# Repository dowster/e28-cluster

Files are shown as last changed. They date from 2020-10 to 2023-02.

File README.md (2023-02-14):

# E28 Cluster Driver

E28 Cluster Driver is (going to be...) an ESP32 based driver board which allows the E28, and possibly E21/E30, cluster to be controlled via custom inputs. For the first version custom input will be done solely via CAN Bus. There won't be any hardcoded message spec, that will be configurable by the user after firmware has been flashed. 

> Main repository is at https://gitlab.com/dowster/e28-cluster

# Build Status


## Hardware

- ESP32
- [GD32VF103RBT6](https://www.mouser.com/ProductDetail/GigaDevice/GD32VF103RBT6)

# ESP IDF Version
v4.2

:)

# E28 Cluster Driver Inputs

Input to the E28 cluster driver shall be done via CAN Bus and possibly with a web based interface for diagnostics, calibration, and configuration. The CAN input shall be configurable so that any value on a can message may be mapped to any of the outputs, allowing the potential for configuring the driver with custom cluster gauge faces. IE: using the econometer to show watts / mile. 

# Instrument Cluster Outputs

## Speedometer Output

The speedometer of the E28 cluster is pulse driven. Approximately 2Hz for every MPH. IE: 50hz -> 25mph, 280hz -> 140mph. Driving the speedometer will advance the odometer automatically. It will also generate a pulse signal that is output to the SI board and the cruise control hardware. 

The speedometer operates on a [UAF 2115 IC](https://darisusgmbh.de/darisus/Elektonikshop/Datenblaetter/ITT/UAF2115.pdf). This IC is a general purpose speedoemter and mileage indidactor IC by ITT Semiconductors. It provides a constant current source to the output pin(s) 10-13 on the E28 cluster plug C2 (white), these four pins are all bridged together, shorting these to ground will provide a pulse to the speedometer. The UAF 2115 also provides an open collector NPN pulse output to drive things such as cruise control. In order to trigger a pulse the speed sensor in the differential would short to ground as each tooth of the gear passed by, these pulses must be atleast 50 microseconds in duration, the max frequency is 10Khz. On the E28 Pin 11 of UAF 2115 is connected to ground, so the division factor is 2^6, I think this is to configure how the odometer tracks distance. 

## Temperature Gauge Output

The temperature guage output will be an open collector NPN output from the E28 cluster driver. The temperature gauge is controlled by varying the current output of pin 12 on connector C1 of the E28 instrument cluster. To control this I'll either use the DAC on the ESP32 or use PWM. I have had some issues with "buzzing" when using PWM but I may just need a higher frequency. 

## Fuel Gauge Output

This is pretty much the same as the temperature gauge but with a different calibration. I'll be using a lower value resistor on the gate of this transistor since the fuel gauge requires more current. This signal is also output to the onboard computer by default. See [OBC Outputs](#OBC-Outputs) for information on how I plan to control the OBC.

## Tachometer Output

The tachometer is controleld by a simple voltage input. I'm thinking a PNP driver for this with PWM control should be fine. 

## Econometer Output

No clue how to do this one yet, haven't really looked into it. 

## Warning Indicators (On PCB)

The warning lights will be controlled via simple solid state relay circuits. Either PNP or NPN transistors controleld via shift registers to save up some pins on the ESP32, if needed. Some of the warning indicators are built onto the instrument cluster's PCB, others are controlled via lights have external wiring. 

### Charge Indicator

Could have many different functions, possibly solid when charging the pack or when the pre-charge resistor is engaged and flashing when a pack error is detected.

### Brake Warning Indicator

TODO

### High Beam Indicator

TODO

### Fog Light Indicator

TODO

### LH Turn Indicator

TODO

### RH Turn Indicator

TODO

### Low Fuel Warning Indicator 

TODO

### "Check" Active Check Control Alarm Indicator

TODO

### Oil Pressure Warning Indicator

This is probably not needed with an EV so that could be modified to be _something else_.

### "Park Brake" Indicator

TODO

### Brake Lining indicator

Haven't seen how this wires up yet, It's on the PCB.

## Warning Indicators (External Wiring)

### Left and Right turn arrows

Probably used to be used on cars where there was only one lamp to tell you that the turn indicators were on. Could be repurposed with a different logo. Background is green.

### Solid Yellow

There's no graphic on this lamp, it's in the 3rd position from left and just has a yellow or orange color filter. 

### EML

Not wired up, says "EML" in black letters with a yellow or orange color filter. 4th position from left

### Solid Green

No graphic on this indiactor, just a solid green. 6th position from left.

### ABS

If the stock ABS is kept this can stay here. Not sure if ABS is used on many swaps but I think that if it is this light may want to be used as a way to kill regen and let the motor coast while ABS figures out what to do. 

## Gearshift Indicators

Seems like even the manual clusters include this plate, or my car has been swapped with an automatic cluster. 

### Transmission Warning Indicator

Shows as a gear with an exclamation mark in the center

### P, R, N, D

Pretty self explanatory

### 3, 2, 1

Show up as individual lamps, for indicating if you've manually selected one of these gears I presume. 

### 1-2-3

This is on single indicator, I presume that it indicates you've disabled overdrive. 

# OBC Outputs

The method for driving the OBC hasn't been determined yet, two options are to just plug the OBC into the instrument cluster and let it run business as usual. The more involved, and possibly better method is to map out the pins on the OBC and manipulate that with the  E28 cluster driver. The main feature I'd like to see out of this is an accuruate range estimate based on pack state of charge and average watts/mile.

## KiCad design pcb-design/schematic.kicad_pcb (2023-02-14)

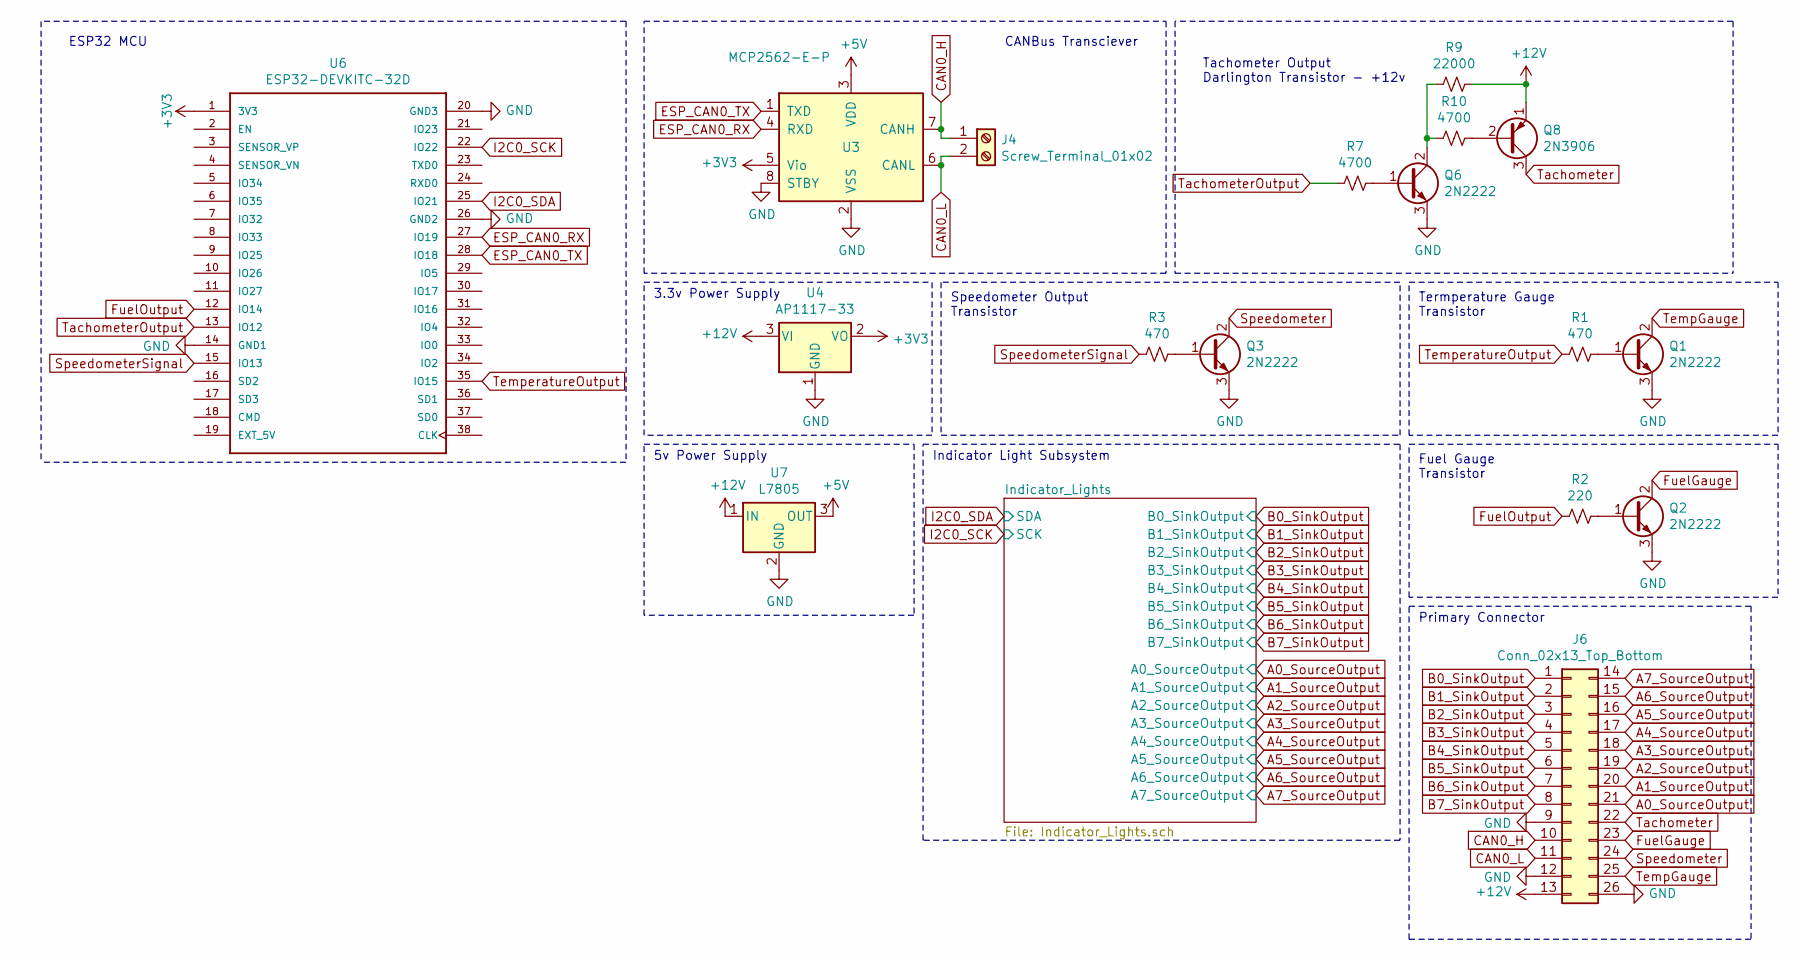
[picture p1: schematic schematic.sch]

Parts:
J4: Screw_Terminal_01x02; TerminalBlock_TE_282834-2_1x02_P2.54mm_Horizontal
J6: Conn_02x13_Top_Bottom; Connector_TE_827881-1
Q1, Q2, Q3, Q6: 2N2222; TO-92_HandSolder
Q8: 2N3906; TO-92_Inline
R1, R3: 470; R_0805_2012Metric
R2: 220; R_0805_2012Metric
R7, R10: 4700; R_0805_2012Metric
R9: 22000; R_0805_2012Metric
U3: MCP2562-E-P; DIP-8_W7.62mm
U4: AP1117-33; SIP3_11.6x8.5mm
U6: ESP32-DEVKITC-32D; MODULE_ESP32-DEVKITC-32D
U7: L7805; SIP3_11.6x8.5mm

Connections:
+5V: U3.3 (VDD), U7.3 (OUT)
+12V: J6.13, Q8.1 (E), R9.1, U4.3 (VI), U7.1 (IN); also elsewhere on the board
A0_SourceOutput: J6.21; also elsewhere on the board
A1_SourceOutput: J6.20; also elsewhere on the board
A2_SourceOutput: J6.19; also elsewhere on the board
A3_SourceOutput: J6.18; also elsewhere on the board
A4_SourceOutput: J6.17; also elsewhere on the board
A5_SourceOutput: J6.16; also elsewhere on the board
A6_SourceOutput: J6.15; also elsewhere on the board
A7_SourceOutput: J6.14; also elsewhere on the board
B0_SinkOutput: J6.1; also elsewhere on the board
B1_SinkOutput: J6.2; also elsewhere on the board
B2_SinkOutput: J6.3; also elsewhere on the board
B3_SinkOutput: J6.4; also elsewhere on the board
B4_SinkOutput: J6.5; also elsewhere on the board
B5_SinkOutput: J6.6; also elsewhere on the board
B6_SinkOutput: J6.7; also elsewhere on the board
B7_SinkOutput: J6.8; also elsewhere on the board
CAN0_H: J4.1, J6.10, U3.7 (CANH)
CAN0_L: J4.2, J6.11, U3.6 (CANL)
ESP_CAN0_RX: U3.4 (RXD), U6.27 (IO19)
ESP_CAN0_TX: U3.1 (TXD), U6.28 (IO18)
FuelGauge: J6.23, Q2.2 (C)
FuelOutput: R2.2, U6.12 (IO14)
GND: J6.9, J6.12, J6.26, Q1.3 (E), Q2.3 (E), Q3.3 (E), Q6.3 (E), U3.2 (VSS), U3.8 (STBY), U4.1 (GND), U6.14 (GND1), U6.20 (GND3), U6.26 (GND2), U7.2 (GND); also elsewhere on the board
I2C0_SCK: U6.22 (IO22); also elsewhere on the board
I2C0_SDA: U6.25 (IO21); also elsewhere on the board
unnamed: Q1.1 (B), R1.1
unnamed: Q2.1 (B), R2.1
unnamed: Q3.1 (B), R3.1
unnamed: Q6.1 (B), R7.1
unnamed: Q6.2 (C), R9.2, R10.2
unnamed: Q8.2 (B), R10.1
Speedometer: J6.24, Q3.2 (C)
SpeedometerSignal: R3.2, U6.15 (IO13)
Tachometer: J6.22, Q8.3 (C)
TachometerOutput: R7.2, U6.13 (IO12)
TempGauge: J6.25, Q1.2 (C)
TemperatureOutput: R1.2, U6.35 (IO15)

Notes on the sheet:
CANBus Transciever
Tachometer Output Darlington Transistor - +12v
3.3v Power Supply
Speedometer Output Transistor
ESP32 MCU
Termperature Gauge Transistor
Fuel Gauge Transistor
Indicator Light Subsystem
Primary Connector
5v Power Supply

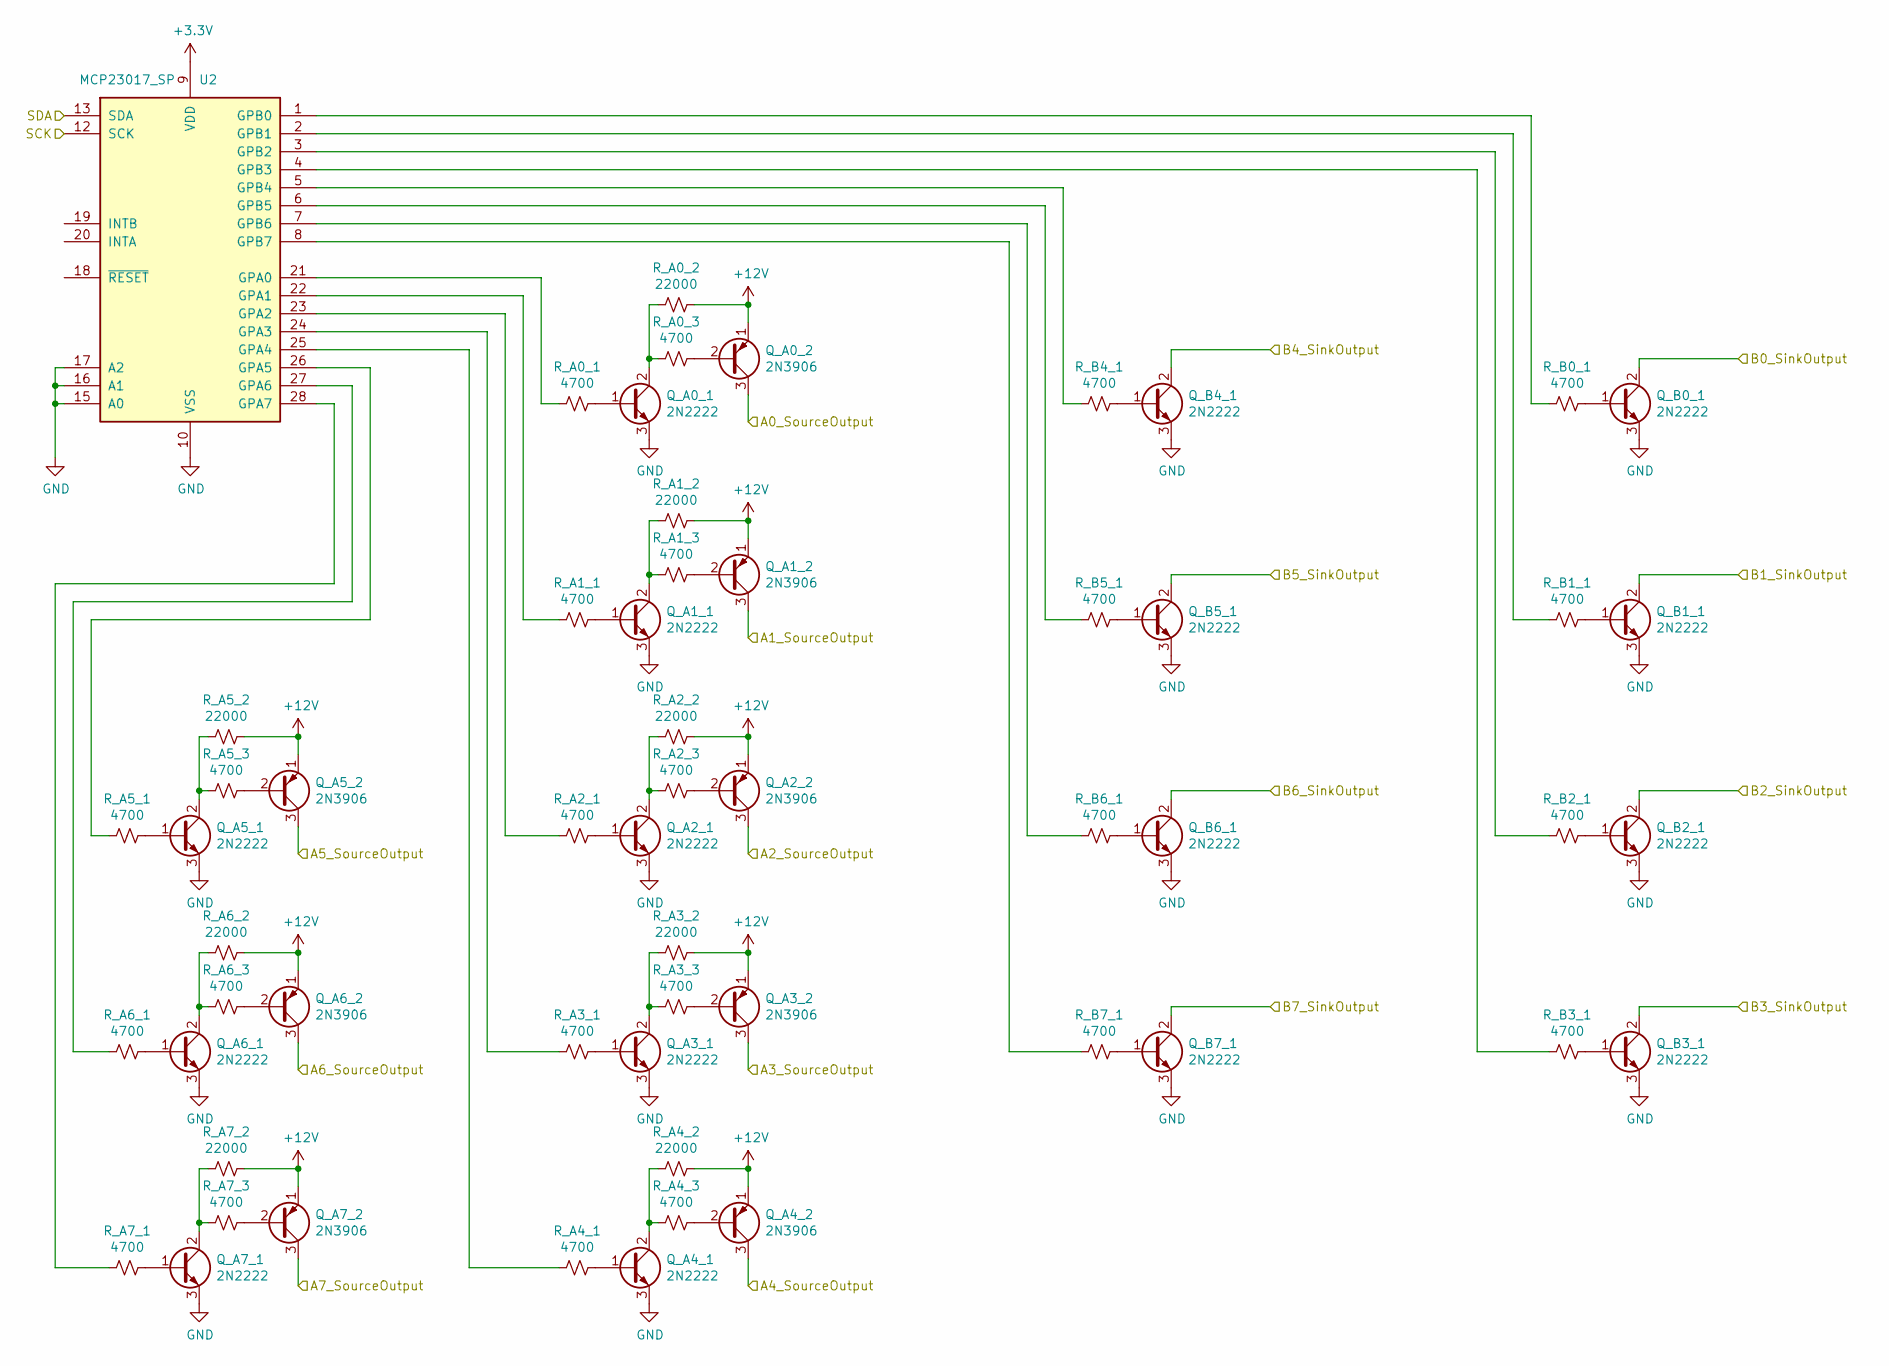
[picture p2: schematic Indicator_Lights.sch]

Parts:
Q_A0_1, Q_A1_1, Q_A2_1, Q_A3_1, Q_A4_1, Q_A5_1, Q_A6_1, Q_A7_1: 2N2222; TO-92_HandSolder
Q_A0_2, Q_A1_2, Q_A2_2, Q_A3_2, Q_A4_2, Q_A5_2, Q_A6_2, Q_A7_2: 2N3906; TO-92_Inline
Q_B0_1, Q_B1_1, Q_B2_1, Q_B3_1, Q_B4_1, Q_B5_1, Q_B6_1, Q_B7_1: 2N2222; TO-92_HandSolder
R_A0_1, R_A0_3, R_A1_1, R_A1_3, R_A2_1, R_A2_3, R_A3_1, R_A3_3, R_A4_1, R_A4_3, R_A5_1, R_A5_3, R_A6_1, R_A6_3, R_A7_1, R_A7_3: 4700; R_0805_2012Metric
R_A0_2, R_A1_2, R_A2_2, R_A3_2, R_A4_2, R_A5_2, R_A6_2, R_A7_2: 22000; R_0805_2012Metric
R_B0_1, R_B1_1, R_B2_1, R_B3_1, R_B4_1, R_B5_1, R_B6_1, R_B7_1: 4700; R_0805_2012Metric
U2: MCP23017_SP; DIP-28_W7.62mm

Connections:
+12V: Q_A0_2.1 (E), Q_A1_2.1 (E), Q_A2_2.1 (E), Q_A3_2.1 (E), Q_A4_2.1 (E), Q_A5_2.1 (E), Q_A6_2.1 (E), Q_A7_2.1 (E), R_A0_2.1, R_A1_2.1, R_A2_2.1, R_A3_2.1, R_A4_2.1, R_A5_2.1, R_A6_2.1, R_A7_2.1; also elsewhere on the board
A0_SourceOutput: Q_A0_2.3 (C); also elsewhere on the board
A1_SourceOutput: Q_A1_2.3 (C); also elsewhere on the board
A2_SourceOutput: Q_A2_2.3 (C); also elsewhere on the board
A3_SourceOutput: Q_A3_2.3 (C); also elsewhere on the board
A4_SourceOutput: Q_A4_2.3 (C); also elsewhere on the board
A5_SourceOutput: Q_A5_2.3 (C); also elsewhere on the board
A6_SourceOutput: Q_A6_2.3 (C); also elsewhere on the board
A7_SourceOutput: Q_A7_2.3 (C); also elsewhere on the board
B0_SinkOutput: Q_B0_1.2 (C); also elsewhere on the board
B1_SinkOutput: Q_B1_1.2 (C); also elsewhere on the board
B2_SinkOutput: Q_B2_1.2 (C); also elsewhere on the board
B3_SinkOutput: Q_B3_1.2 (C); also elsewhere on the board
B4_SinkOutput: Q_B4_1.2 (C); also elsewhere on the board
B5_SinkOutput: Q_B5_1.2 (C); also elsewhere on the board
B6_SinkOutput: Q_B6_1.2 (C); also elsewhere on the board
B7_SinkOutput: Q_B7_1.2 (C); also elsewhere on the board
GND: Q_A0_1.3 (E), Q_A1_1.3 (E), Q_A2_1.3 (E), Q_A3_1.3 (E), Q_A4_1.3 (E), Q_A5_1.3 (E), Q_A6_1.3 (E), Q_A7_1.3 (E), Q_B0_1.3 (E), Q_B1_1.3 (E), Q_B2_1.3 (E), Q_B3_1.3 (E), Q_B4_1.3 (E), Q_B5_1.3 (E), Q_B6_1.3 (E), Q_B7_1.3 (E), U2.10 (VSS), U2.15 (A0), U2.16 (A1), U2.17 (A2); also elsewhere on the board
I2C0_SCK: U2.12 (SCK); also elsewhere on the board
I2C0_SDA: U2.13 (SDA); also elsewhere on the board
unnamed: Q_A0_1.1 (B), R_A0_1.1
unnamed: Q_A0_1.2 (C), R_A0_2.2, R_A0_3.2
unnamed: Q_A0_2.2 (B), R_A0_3.1
unnamed: Q_A1_1.1 (B), R_A1_1.1
unnamed: Q_A1_1.2 (C), R_A1_2.2, R_A1_3.2
unnamed: Q_A1_2.2 (B), R_A1_3.1
unnamed: Q_A2_1.1 (B), R_A2_1.1
unnamed: Q_A2_1.2 (C), R_A2_2.2, R_A2_3.2
unnamed: Q_A2_2.2 (B), R_A2_3.1
unnamed: Q_A3_1.1 (B), R_A3_1.1
unnamed: Q_A3_1.2 (C), R_A3_2.2, R_A3_3.2
unnamed: Q_A3_2.2 (B), R_A3_3.1
unnamed: Q_A4_1.1 (B), R_A4_1.1
unnamed: Q_A4_1.2 (C), R_A4_2.2, R_A4_3.2
unnamed: Q_A4_2.2 (B), R_A4_3.1
unnamed: Q_A5_1.1 (B), R_A5_1.1
unnamed: Q_A5_1.2 (C), R_A5_2.2, R_A5_3.2
unnamed: Q_A5_2.2 (B), R_A5_3.1
unnamed: Q_A6_1.1 (B), R_A6_1.1
unnamed: Q_A6_1.2 (C), R_A6_2.2, R_A6_3.2
unnamed: Q_A6_2.2 (B), R_A6_3.1
unnamed: Q_A7_1.1 (B), R_A7_1.1
unnamed: Q_A7_1.2 (C), R_A7_2.2, R_A7_3.2
unnamed: Q_A7_2.2 (B), R_A7_3.1
unnamed: Q_B0_1.1 (B), R_B0_1.1
unnamed: Q_B1_1.1 (B), R_B1_1.1
unnamed: Q_B2_1.1 (B), R_B2_1.1
unnamed: Q_B3_1.1 (B), R_B3_1.1
unnamed: Q_B4_1.1 (B), R_B4_1.1
unnamed: Q_B5_1.1 (B), R_B5_1.1
unnamed: Q_B6_1.1 (B), R_B6_1.1
unnamed: Q_B7_1.1 (B), R_B7_1.1
unnamed: R_A0_1.2, U2.21 (GPA0)
unnamed: R_A1_1.2, U2.22 (GPA1)
unnamed: R_A2_1.2, U2.23 (GPA2)
unnamed: R_A3_1.2, U2.24 (GPA3)
unnamed: R_A4_1.2, U2.25 (GPA4)
unnamed: R_A5_1.2, U2.26 (GPA5)
unnamed: R_A6_1.2, U2.27 (GPA6)
unnamed: R_A7_1.2, U2.28 (GPA7)
unnamed: R_B0_1.2, U2.1 (GPB0)
unnamed: R_B1_1.2, U2.2 (GPB1)
unnamed: R_B2_1.2, U2.3 (GPB2)
unnamed: R_B3_1.2, U2.4 (GPB3)
unnamed: R_B4_1.2, U2.5 (GPB4)
unnamed: R_B5_1.2, U2.6 (GPB5)
unnamed: R_B6_1.2, U2.7 (GPB6)
unnamed: R_B7_1.2, U2.8 (GPB7)

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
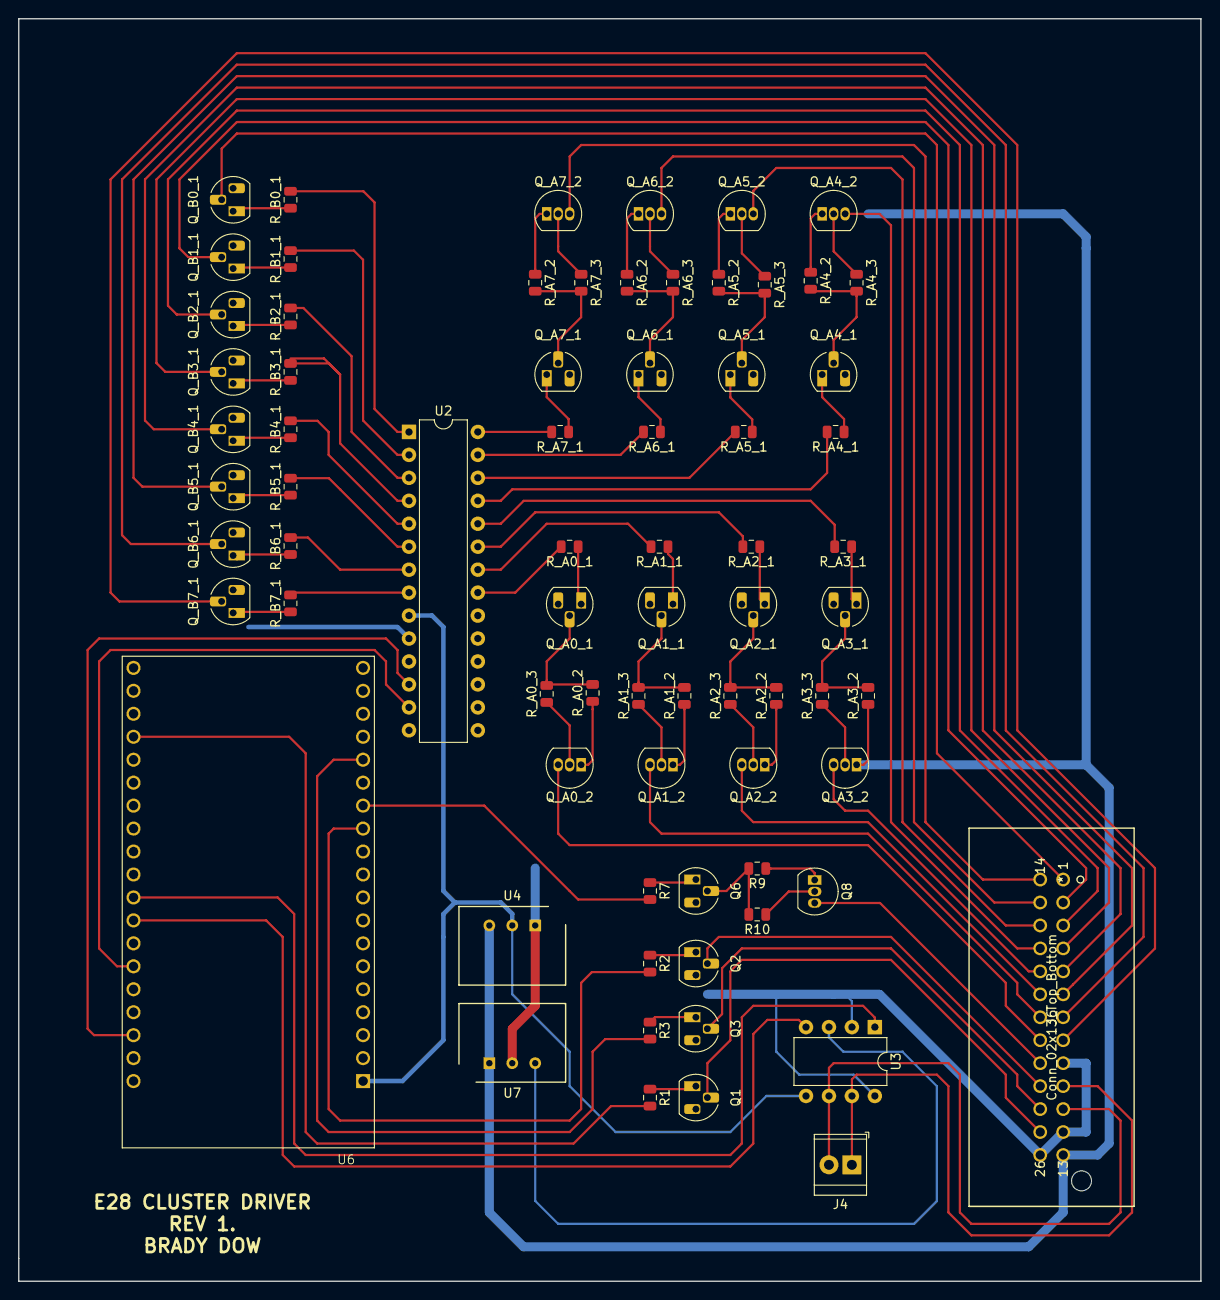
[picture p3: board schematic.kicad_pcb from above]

Board: 2 copper layers, 130.8 x 139.7 mm, 74 parts (0 on the bottom side), 88 nets.

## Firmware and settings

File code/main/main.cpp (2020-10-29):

/* Hello World Example

   This example code is in the Public Domain (or CC0 licensed, at your option.)

   Unless required by applicable law or agreed to in writing, this
   software is distributed on an "AS IS" BASIS, WITHOUT WARRANTIES OR
   CONDITIONS OF ANY KIND, either express or implied.
*/

// This is to fix a typo in the current 4.2 release of esp-idf.
// Remove this once PR https://github.com/espressif/esp-idf/pull/5148 is merged. 
#ifdef __cplusplus
#define _cplusplus
#endif


#include <stdio.h>
#include <string.h>

#include <driver/gpio.h>
#include <driver/dac.h>
#include <freertos/FreeRTOS.h>
#include <freertos/task.h>
#include <freertos/queue.h>
#include <freertos/semphr.h>
#include <esp_system.h>
#include <esp_spi_flash.h>
#include <esp_err.h>
#include <esp_log.h>

#include "include/fuel_gauge.h"
#include "include/speedometer_gauge.h"
#include "include/tachometer_gauge.h"
#include "include/simpbms_comms.h"
#include "include/indicator_lights.h"
#include "include/canbus.h"

#include "include/temp_gauge.h"
#include "include/wifi_controls.h"

#define ID_ENGINE_SPEED_TEMP      0x35B
#define ID_VEHICLE_SPEED          0x29B
#define INDICATOR_LIGHTS_EXPANDER 0x20
#define GPIO_OUTPUT_IO_0          18

extern "C" {
    void app_main(void);
}

TempGauge tempGauge;
WifiControls wifiControls;

void app_main(void)
{
    printf("Hello world!\n");

    /* Print chip information */
    esp_chip_info_t chip_info;
    esp_chip_info(&chip_info);
    printf("This is ESP32 chip with %d CPU cores, WiFi%s%s, ",
            chip_info.cores,
            (chip_info.features & CHIP_FEATURE_BT) ? "/BT" : "",
            (chip_info.features & CHIP_FEATURE_BLE) ? "/BLE" : "");

    printf("silicon revision %d, ", chip_info.revision);

    printf("%dMB %s flash\n", spi_flash_get_chip_size() / (1024 * 1024),
            (chip_info.features & CHIP_FEATURE_EMB_FLASH) ? "embedded" : "external");

    //Initialize NVS
    esp_err_t ret = nvs_flash_init();
    if (ret == ESP_ERR_NVS_NO_FREE_PAGES || ret == ESP_ERR_NVS_NEW_VERSION_FOUND) {
      ESP_ERROR_CHECK(nvs_flash_erase());
      ret = nvs_flash_init();
    }
    ESP_ERROR_CHECK(ret);

    wifiControls = WifiControls();
    ESP_LOGI("INIT", "CONNECTING TO WIFI NETWORK");
    wifiControls.connectToStation();
    ESP_LOGI("INIT", "STARTING WEBSERVER");
    wifiControls.setupServer();

    tempGauge = TempGauge(DAC_CHANNEL_2);
    setup_fuel_gauge(DAC_CHANNEL_1, GPIO_NUM_NC);
    wifiControls.setTempGauge(&tempGauge);

    setup_speedometer_gauge(GPIO_NUM_4);
    setup_tachometer_gauge(GPIO_NUM_5);

    ESP_LOGI("INIT", "Initializing canbus");
    can_configure();
    xTaskCreate(can_receive_task, "CAN_rx", 4096, NULL, CAN_RX_TASK_PRIO, NULL);

    indicators_init(INDICATOR_LIGHTS_EXPANDER);
    xTaskCreate(indicator_lights, "Indicator Lamp Update", configMINIMAL_STACK_SIZE * 6, NULL, 5, NULL);
    
    //write_to_speedometer(3);

    for (uint32_t i = 120; i >= 1; i--) {
        printf("Restarting in %d seconds...\n", i);
        vTaskDelay(1000 / portTICK_PERIOD_MS);
        
        write_to_fuel_gauge(i / 1.2);
        //tempGauge.write_to_temp_gauge(i + 100);

        write_to_speedometer(i);
        write_to_tachometer(i * 40);
    }
    printf("Restarting now.\n");
    fflush(stdout);
    esp_restart();
}

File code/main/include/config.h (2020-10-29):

#include <driver/gpio.h>

/** i2c config **/
#define I2C_FREQ_HZ 100000
#define SDA_GPIO GPIO_NUM_21
#define SCL_GPIO GPIO_NUM_22

/** CAN bus config **/
/**
 * Priority of the FreeRTOS task which
 * checks for and handles messages
 * received on the CAN bus.
 */
#define CAN_RX_TASK_PRIO 9

/**
 * GPIO pin for the CAN bus TX.
 */
#define CAN_TX_GPIO_NUM  GPIO_NUM_18

/**
 * GPIO pin for the CAN bus TX.
 */
#define CAN_RX_GPIO_NUM  GPIO_NUM_19

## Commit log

2019-11-21 Added the circuit for driving the speedometer pulses. Speedometer pulse is approximately 2hz for every mph. Minimum is around 10-20hz.
2019-11-25 Schematic updates, learning KiCad a bit.
    [pcb-design.kicad_pcb, pcb-design.sch, schematic.sch]
2019-12-16 Fill out the functions for the indicator lights portion.
    Include link to the MCP23017 datasheet in the header. Link will probably die tomorrow.
2019-12-16 i think i fixed some whoopsies but my local compiler seems either broken or out of date.
    [indicator_lights.c, speedometer_gauge.c]
2019-12-17 Added Tachometer circuit to schematic
    [schematic.sch]
2020-01-05 Including the Adafruit driver for the i2c gpio expander as a reference.
2020-02-29 Indicator lights i2c debugging (#1)
    i2c has been debugged. The main issue was probably me not re-initing the i2c driver properly and even with the library I pulled in I need to make the first config call twice to account for a corrupt bus state at boot.
    * Got this working with IDF v4.0
    * Put the mcp23017 library into indicator lights.
    * Split things out into header files.
    [config.h, fuel_gauge.c, indicator_lights.c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]
2020-03-10 Add initial attempt at generating schematics
2020-03-10 Schematic is an unknown file type
2020-03-10 pcb-design.pro didn't have an associated pcb-design.sch. Trying schematic.
2020-03-10 add the schematic cache library, might contain components.
2020-03-10 Switch to use latest image eeshow
2020-03-10 Switch travis ci to add multiple files to the release
2023-02-14 Don't track the workspace file and don't track .sch-bak data.
    Created a schematic for the indicator lights circuit.
    [Indicator_Lights.sch, TachometerOutput.sch, indicator-lights.sch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]
2023-02-14 Checking in schematic files
    [schematic.kicad_pcb, schematic.sch]
2023-02-14 Moved some files around
    [indicator-lights.sch, schematic.sch]
2023-02-14 Swapped the esp32 symbol and footprint to be one for the dev modules so I can just populate the boards with standoffs.
    Wired up some more nets and made the layout a little prettier.
    [Indicator_Lights.sch, TachometerOutput.sch, schematic.kicad_pcb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]
2023-02-14 Added TE 827881-1 connector and footprint re-arranged schematic
    [Indicator_Lights.sch, schematic.kicad_pcb, schematic.sch]
2023-02-14 Final changes for Rev 1 board, ordered 10/06/2020
    [schematic.kicad_pcb, schematic.sch]
2023-02-14 Updated resistor footprints to 0805 which had better coverage for JLCPCB basic parts.
    [Indicator_Lights.sch, schematic.kicad_pcb, schematic.sch]
2023-02-14 Trying to add a pdf of the pcb layout
2023-02-14 Revert "Trying to add a pdf of the pcb layout"
    This reverts commit b56f1969f75d8c114cc69d4ada7bfdc8b18707b8.
2023-02-14 Squashed commit of the following:
    commit 3feebbdd7fc9a19dcfe87aea05ec82215f171dbb
    Author: dowster <brady@dowster.net>
    Date: Mon Feb 13 23:49:32 2023 -0600
    add potential backup MCU
    commit 7657e025624eaa3ad175eda664276684d823e8da
    Author: dowster <brady@dowster.net>
    Date: Sun Jun 14 00:02:21 2020 -0500
    Revert "Trying to add a pdf of the pcb layout"
    commit 2fa9ff3b8e4192675af680a6f10c74fef6b1e3eb
    Author: dowster <brady@dowster.net>
    Date: Sun Jun 14 00:00:47 2020 -0500
    Trying to add a pdf of the pcb layout
    commit dd21b1a7d9b37009cc4babccdf1aa4f396be8d7d
    Author: dowster <brady@dowster.net>
    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
    [Indicator_Lights.sch, schematic.kicad_pcb, schematic.sch]

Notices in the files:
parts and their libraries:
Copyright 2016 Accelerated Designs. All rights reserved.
